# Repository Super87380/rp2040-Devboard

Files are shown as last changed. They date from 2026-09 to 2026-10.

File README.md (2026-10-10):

# RP2040 Devboard

This custom RP2040 Devboard features a built in 6 axis IMU, onboard LED, and 26 accessible GPIO Pins in a smaller package than a normal raspberry pi pico.

**Why did I make this?**\
I created this project to improve my PCB design skills, learn more about designing circuits around an MCU, and how to use an IMU. These skills I learnt will help me with my short term goal of making a device similar to a google home, and my long term goal of creating a thrust vector controlled rocket.

**What makes this devboard unique?**
- Built-in IMU which is not something ive seen
- It has a onboard LED that can be programmed to do anything you want (if that incudes turning on or off)
- Pretty compact package, I mean it is smaller than an official raspberry pi pico and has a built-in IMU





**How to assemble**\
Assembling this PCB is pretty straightforward if you have experience soldering SMD components. Or you can just order it assembled through JLCPCBA or other similar services.
I recommend getting a stencil with your PCB's so that it's easier to apply the thermal paste. It's also very helpful to have a hotplate or soldering oven but it is possible to solder the components with just a soldering iron or a hot air gun.

**How to Flash**\
Flashing the MCU is super simple, simply hold down the boot button and plug the board into your computer. It then shows up as a USB drive in file explorer in which you can then drag in your firmware of choice like the simple onboard LED blinking provided.

**BOM**\
Prices in USD
Hyperlink doesn't work, must copy and paste link into search bar.

| Part | Notes | Link | Quantity | Price Per Unit | Total |
| --- | --- | --- | --- | --- | --- |
| RP2040 | RP2040 MCU (only need 1, added 2 incase mistakes are made) | https://www.lcsc.com/product-detail/C2040.html | 2 | 0.9975 | 2.00 |
| W25Q16JVZPIQ | 16 Mbit (only need 1, added 2 incase mistakes are made) | https://www.lcsc.com/product-detail/C2456208.html | 2 | 1.92 | 3.84 |
| BMI323 | 6 Axis | https://www.lcsc.com/product-detail/C5368700.html | 1 | 3.26 | 3.26 |
| L327S120D11L | 12 Mhz | https://www.lcsc.com/product-detail/C5917263.html | 1 | 0.39 | 0.39 |
| TYPE-C16P3MDDGP073 | USB-C Receptacle | https://www.lcsc.com/product-detail/C2965608.html | 1 | 0.58 | 0.58 |
| P6E19A-602530-B1P | 19 Pin Male Headers, only need 2 (min 5) | https://www.lcsc.com/product-detail/C49451383.html | 5 | 0.0733 | 0.37 |
| 61300311121 | 3 Pin Male Headers, only need 1 (min 5) | https://www.lcsc.com/product-detail/C32713269.html | 5 | 0.0246 | 0.12 |
| CC0402KRX7R8BB104 | 0.1uf 0402 Capacitor, only need 13 (minimum 100) | https://www.lcsc.com/product-detail/C105883.html | 100 | 0.0073 | 0.73 |
| CGA0402X5R105K500GT | 1uf 0402 Capacitor, only need 2 (minimum 20) | https://www.lcsc.com/product-detail/C6119811.html | 20 | 0.0263 | 0.53 |
| TCC0603X5R106M350CT | 10uf 0603 Capacitor, only need 2 (minimum 10) | https://www.lcsc.com/product-detail/C22392391.html | 10 | 0.0542 | 0.54 |
| GJM1555C1H120GB01D | 12pf 0402 Capacitor, only need 2 (minimum 20) | https://www.lcsc.com/product-detail/C161305.html | 20 | 0.0306 | 0.61 |
| RC0402FR-075K1L | 5.1k 0402 Resistor, only need 2 (minimum 100) | https://www.lcsc.com/product-detail/C105872.html | 100 | 0.0025 | 0.25 |
| SR0402FR-7T10KL | 10k 0402 Resistor, only need 1 (minimum 20) | https://www.lcsc.com/product-detail/C854480.html | 20 | 0.024 | 0.48 |
| AC0402JR-074K7L | 4.7k 0402 Resistor, only need 2 (minimum 100) | https://www.lcsc.com/product-detail/C144709.html | 100 | 0.0023 | 0.23 |
| RC0402JR-071KL | 1k 0402 Resistor, only need 2 (minimum 100) | https://www.lcsc.com/product-detail/C105637.html | 100 | 0.0029 | 0.29 |
| RC0402FR-07270RL | 270 0402 Resistor, only need 1 (minimum 100) | https://www.lcsc.com/product-detail/C163474.html | 100 | 0.0019 | 0.19 |
| RCS040227R0FKED | 27 0402 Resistor, only need 2 (minimum 10) | https://www.lcsc.com/product-detail/C2100055.html | 10 | 0.0373 | 0.37 |
| CSL1104WBDW1 | 0603 White LED | https://www.lcsc.com/product-detail/C5603527.html | 1 | 0.311 | 0.31 |
| HX TS253015A2P 160gf | Boot Button, only need 1 (minimum 5) | https://www.lcsc.com/product-detail/C25168826.html | 5 | 0.1006 | 0.50 |
| PCB | Comes with 5 | | 1 | 2.1 | 2.10 |
| Solder Paste | Solder paste for soldering SMD components | https://www.amazon.ca/Chip-Quik-Smooth-Solder-Syringe/dp/B096BM9P32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 | 1 | 9.64 | 9.64 |
| | | | | Sub Total: | 27.33 |
| | | | | Shipping: | 8.68 |
| | | | | Total: | 36.01 |

PCB Quote\


This project was made possible through the funding of Hackclub and Forge.\
More information on the build and design process can be found in my [Forge Project](https://forge.hackclub.com/projects/2720)

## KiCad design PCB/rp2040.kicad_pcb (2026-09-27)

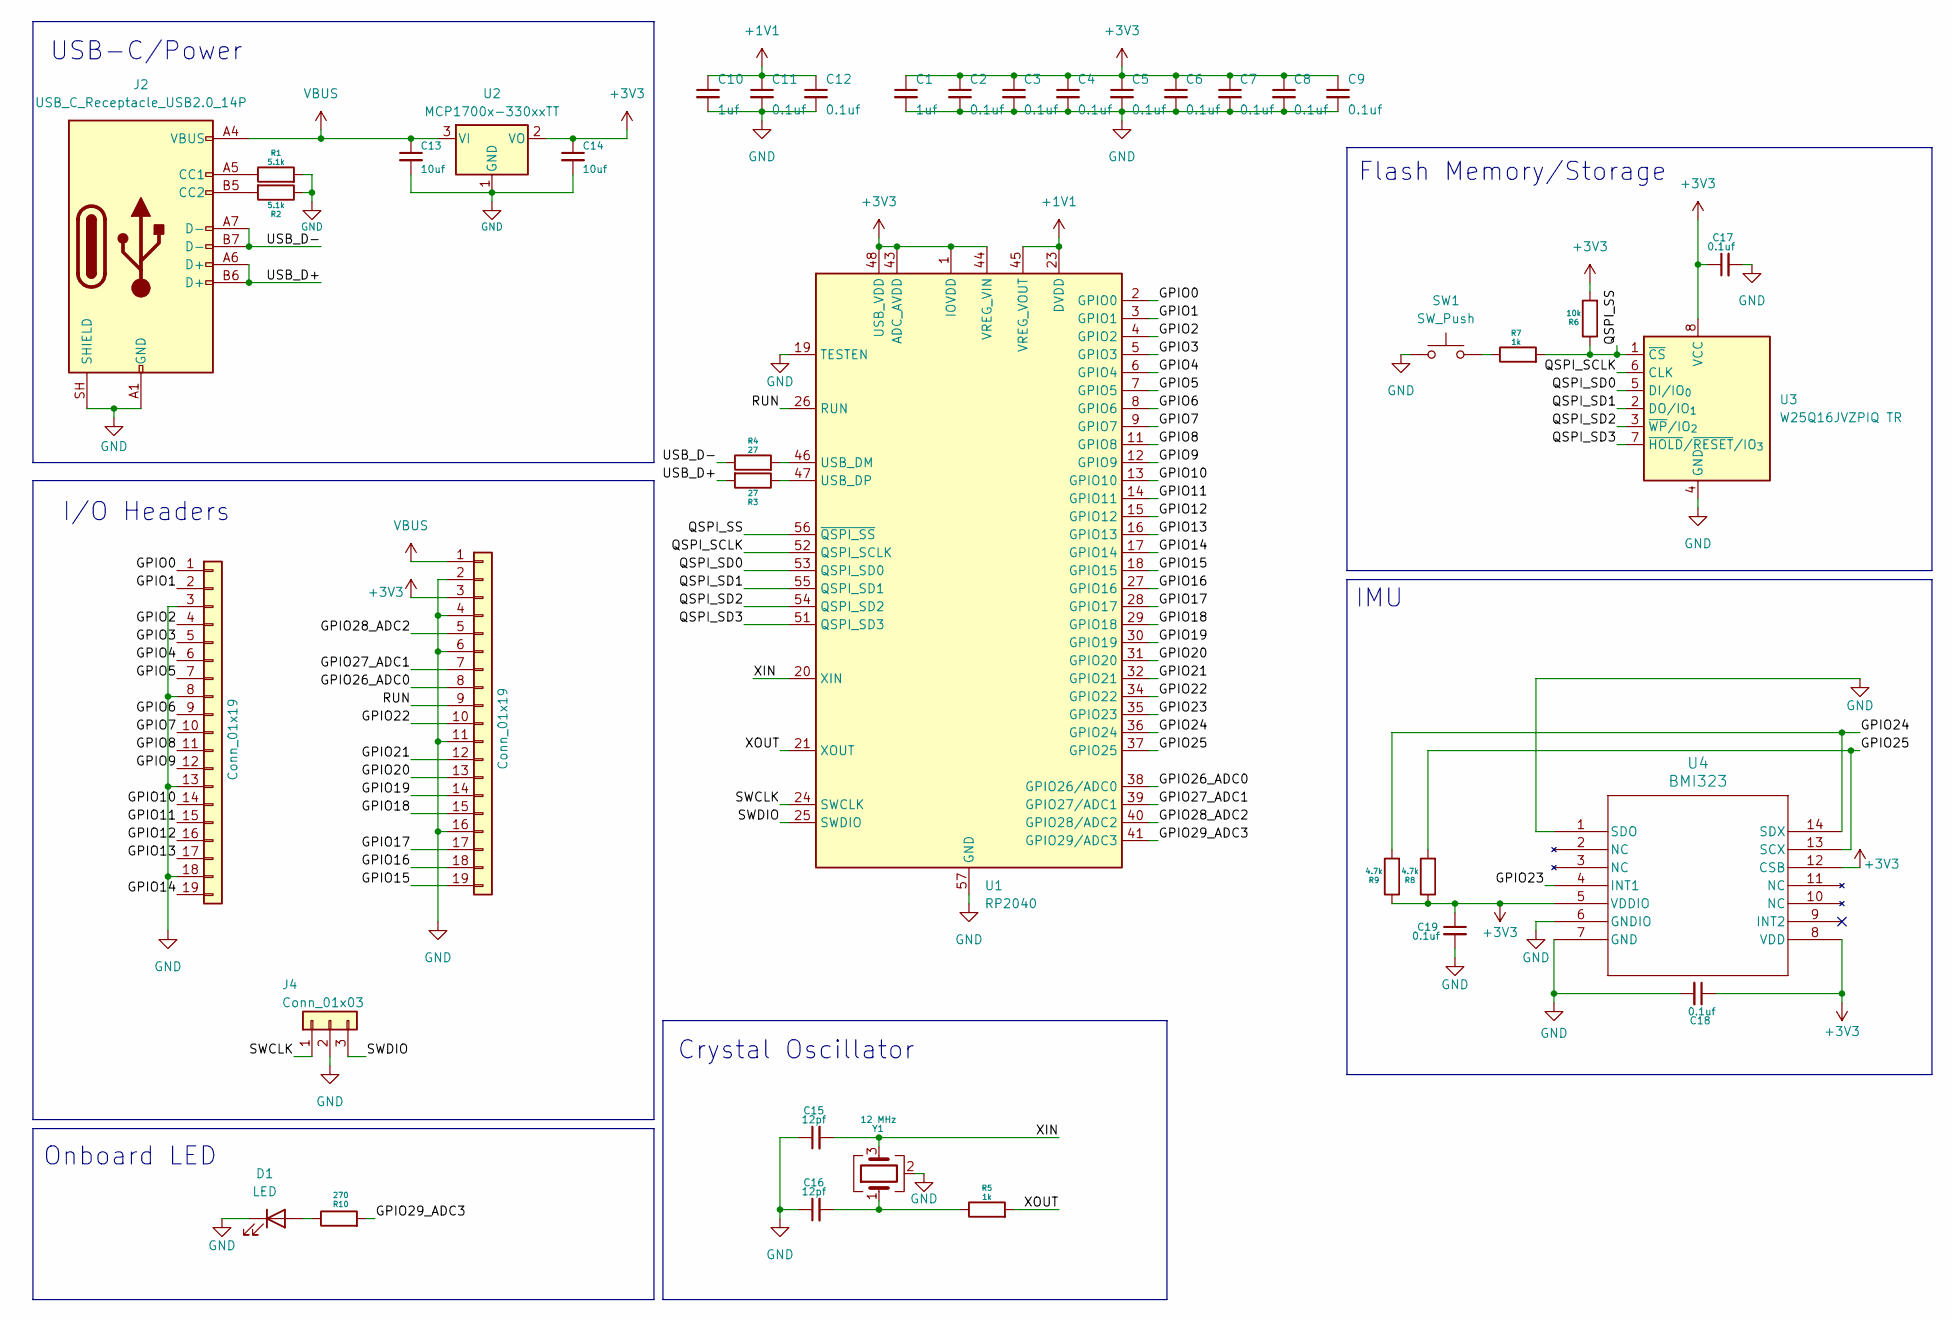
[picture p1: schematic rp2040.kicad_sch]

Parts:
C1, C10: 1uf; C_0402_1005Metric
C2, C3, C4, C5, C6, C7, C8, C9, C11, C12, C17, C18, C19: 0.1uf; C_0402_1005Metric
C13, C14: 10uf; C_0603_1608Metric
C15, C16: 12pf; C_0402_1005Metric
D1: LED; LED_0603_1608Metric
J2: USB_C_Receptacle_USB2.0_14P; TYPE-C-31-M-14
J4: Conn_01x03; PinHeader_1x03_P2.54mm_Vertical
J5, J6: Conn_01x19; PinHeader_1x19_P2.54mm_Vertical
R1, R2: 5.1k; R_0402_1005Metric
R3, R4: 27; R_0402_1005Metric
R5, R7: 1k; R_0402_1005Metric
R6: 10k; R_0402_1005Metric
R8, R9: 4.7k; R_0402_1005Metric
R10: 270; R_0402_1005Metric
SW1: SW_Push; SW_SPST_B3U-1000P
U1: RP2040; QFN-56-1EP_7x7mm_P0.4mm_EP3.2x3.2mm
U2: MCP1700x-330xxTT; SOT-23
U3: W25Q16JVZPIQ TR; Winbond_USON-8-1EP_3x2mm_P0.5mm_EP0.2x1.6mm
U4: BMI323; BMI323_BOS
Y1: 12 MHz; Crystal_SMD_3225-4Pin_3.2x2.5mm

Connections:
+1V1: C10.1, C11.1, C12.1, U1.23 (DVDD), U1.45 (VREG_VOUT), U1.50 (DVDD)
+3V3: C1.1, C2.1, C3.1, C4.1, C5.1, C6.1, C7.1, C8.1, C9.1, C14.1, C17.1, C18.1, C19.1, J6.3, R6.2, R8.1, R9.1, U1.1 (IOVDD), U1.10 (IOVDD), U1.22 (IOVDD), U1.33 (IOVDD), U1.42 (IOVDD), U1.43 (ADC_AVDD), U1.44 (VREG_VIN), U1.48 (USB_VDD), U1.49 (IOVDD), U2.2 (VO), U3.8 (VCC), U4.5 (VDDIO), U4.8 (VDD), U4.12 (CSB)
/GPIO0: J5.1, U1.2 (GPIO0)
/GPIO1: J5.2, U1.3 (GPIO1)
/GPIO2: J5.4, U1.4 (GPIO2)
/GPIO3: J5.5, U1.5 (GPIO3)
/GPIO4: J5.6, U1.6 (GPIO4)
/GPIO5: J5.7, U1.7 (GPIO5)
/GPIO6: J5.9, U1.8 (GPIO6)
/GPIO7: J5.10, U1.9 (GPIO7)
/GPIO8: J5.11, U1.11 (GPIO8)
/GPIO9: J5.12, U1.12 (GPIO9)
/GPIO10: J5.14, U1.13 (GPIO10)
/GPIO11: J5.15, U1.14 (GPIO11)
/GPIO12: J5.16, U1.15 (GPIO12)
/GPIO13: J5.17, U1.16 (GPIO13)
/GPIO14: J5.19, U1.17 (GPIO14)
/GPIO15: J6.19, U1.18 (GPIO15)
/GPIO16: J6.18, U1.27 (GPIO16)
/GPIO17: J6.17, U1.28 (GPIO17)
/GPIO18: J6.15, U1.29 (GPIO18)
/GPIO19: J6.14, U1.30 (GPIO19)
/GPIO20: J6.13, U1.31 (GPIO20)
/GPIO21: J6.12, U1.32 (GPIO21)
/GPIO22: J6.10, U1.34 (GPIO22)
/GPIO23: U1.35 (GPIO23), U4.4 (INT1)
/GPIO24: R9.2, U1.36 (GPIO24), U4.14 (SDX)
/GPIO25: R8.2, U1.37 (GPIO25), U4.13 (SCX)
/GPIO26_ADC0: J6.8, U1.38 (GPIO26/ADC0)
/GPIO27_ADC1: J6.7, U1.39 (GPIO27/ADC1)
/GPIO28_ADC2: J6.5, U1.40 (GPIO28/ADC2)
/GPIO29_ADC3: R10.2, U1.41 (GPIO29/ADC3)
/QSPI_SCLK: U1.52 (QSPI_SCLK), U3.6 (CLK)
/QSPI_SD0: U1.53 (QSPI_SD0), U3.5 (DI/IO_{0})
/QSPI_SD1: U1.55 (QSPI_SD1), U3.2 (DO/IO_{1})
/QSPI_SD2: U1.54 (QSPI_SD2), U3.3 (~WP/IO_{2})
/QSPI_SD3: U1.51 (QSPI_SD3), U3.7 (~HOLD/~RESET/IO_{3})
/QSPI_SS: R6.1, R7.2, U1.56 (~QSPI_SS), U3.1 (~CS)
/RUN: J6.9, U1.26 (RUN)
/SWCLK: J4.1, U1.24 (SWCLK)
/SWDIO: J4.3, U1.25 (SWDIO)
/USB_D+: J2.A6 (D+), J2.B6 (D+), R3.2
/USB_D-: J2.A7 (D-), J2.B7 (D-), R4.1
/XIN: C15.2, U1.20 (XIN), Y1.3
/XOUT: R5.2, U1.21 (XOUT)
GND: C1.2, C2.2, C3.2, C4.2, C5.2, C6.2, C7.2, C8.2, C9.2, C10.2, C11.2, C12.2, C13.2, C14.2, C15.1, C16.1, C17.2, C18.2, C19.2, D1.1 (K), J2.A1 (GND), J2.A12 (GND), J2.B1 (GND), J2.B12 (GND), J2.SH (SHIELD), J4.2, J5.3, J5.8, J5.13, J5.18, J6.2, J6.4, J6.6, J6.11, J6.16, R1.2, R2.1, SW1.1, U1.19 (TESTEN), U1.57 (GND), U2.1 (GND), U3.4 (GND), U4.1 (SDO), U4.6 (GNDIO), U4.7 (GND), Y1.2 (G), Y1.4 (G)
unnamed: C16.2, R5.1, Y1.1
unnamed: D1.2 (A), R10.1
unnamed: J2.A5 (CC1), R1.1
unnamed: J2.B5 (CC2), R2.2
unnamed: R7.1, SW1.2
unnamed: R4.2, U1.46 (USB_DM)
unnamed: R3.1, U1.47 (USB_DP)
VBUS: C13.1, J2.A4 (VBUS), J2.A9 (VBUS), J2.B4 (VBUS), J2.B9 (VBUS), J6.1, U2.3 (VI)

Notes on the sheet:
I/O Headers
Crystal Oscillator
Onboard LED
Flash Memory/Storage
IMU
USB-C/Power

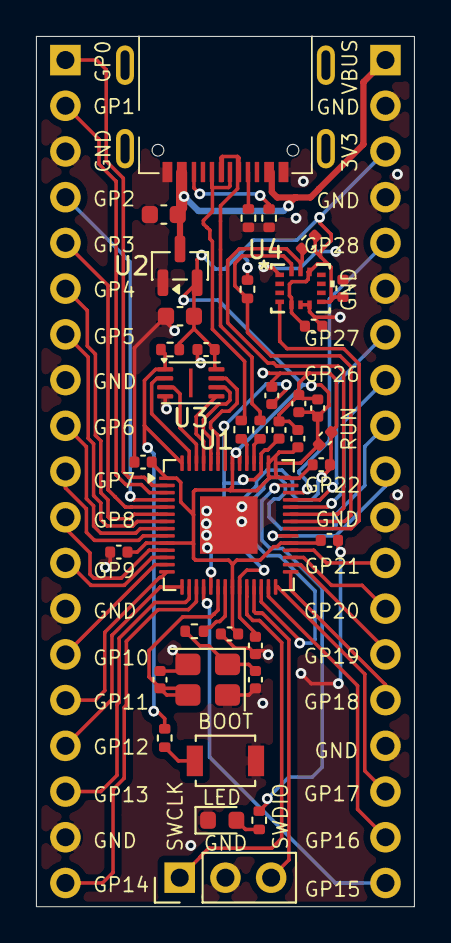
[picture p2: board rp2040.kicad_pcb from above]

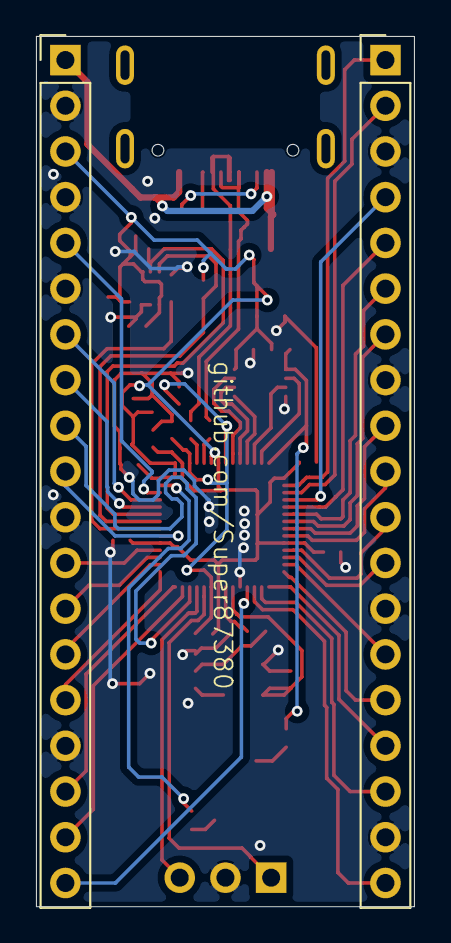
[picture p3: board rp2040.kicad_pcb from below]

Board: 2 copper layers, 21.0 x 48.3 mm, 40 parts (2 on the bottom side), 54 nets.

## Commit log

2026-09-27 Rename RP2040 Devboard IMU.xlsx to BOM.xlsx
    [BOM.xlsx]
2026-09-27 Rename RP2040 Devboard IMU - Sheet1.csv to BOM.csv
    [BOM.csv]
2026-09-27 Rename RP2040 Devboard.zip to Gerber.zip
2026-09-27 Create PCB Source Files
2026-10-10 Rename RP2040 Devboard BOM - Sheet1 (1).csv to BOM.csv
    [BOM.csv]
2026-10-10 Rename RP2040 Devboard BOM - Sheet1.csv to BOM.csv
    [BOM.csv]
